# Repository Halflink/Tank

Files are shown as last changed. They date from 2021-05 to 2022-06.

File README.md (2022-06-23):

# Tank Project

### PROJECT
| Project name: | Halflink/Tank |
| --- | --- |
| Author: | Jeroen van Zwam |
| Date: | Summer 2019 |  
| Project type: | Raspberry Pi |

Additional information can be found in ./docs. Please read /docs/index.md for information on the documents.

### Executable

- Start ManualTank.py for console controlled running
- Start AutoTank.py for automatic running

### PROJECT DESCRIPTION
I started this project to see what you could do with a Pi. The goal is to create a
tracked robot which can roam around automatically.<br/>
Currently there are two operating modes:

1) roaming using ultrasonic sensor, by starting AutoTank.py
2) remote control using Xbox controller, by starting ManualTank.py

I chose the Devastator chassis as it came with the DC motors and it looks neat.

### PI INSTALLATION NOTES

- Set up SSH
- Set up WIFI
- Set up shared folder
- Set up Xbox controller https://pimylifeup.com/xbox-controllers-raspberry-pi/
- Use init.json to set up the GPIO ports

### PARTS LIST*

- Raspberry Py 3 zero
- Devastator Tank Mobile Robot Platform (Metal DC Gear Motor)
  https://elektronicavoorjou.nl/product/devastator-mobile-robot-metal-motor/
- L298N H-bridge Stepper Motor Driver
  https://www.kiwi-electronics.nl/l298n-module
- UBEC
  https://www.kiwi-electronics.nl/index.php?route=product/isearch&search=UBEC&description=true
- Xbox game console with bluetooth.
- HC-SR04 ultrasone sensor
  https://elektronicavoorjou.nl/product/hc-sr04-sensor/
- Custom holder for HC-SR04
  https://www.thingiverse.com/thing:2592461
  Designed by: https://www.thingiverse.com/alainducros/designs
  Manufactured by https://www.instagram.com/saydamcustomshop/

*) Please note that only the major parts are mentioned

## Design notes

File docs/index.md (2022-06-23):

#Index

## Design documents
**Fixation_articulée_pour_HC-SR04.zip**  
Thingiverse file for 3d printing custom part

**tank.fzz**  
This file contains the breadboard schema drawing fot my tank project.
.fzz is a fritzing file. You can download fritzing from https://fritzing.org/.

**tank_bb.png**
This file shows the breadboard of tank.fzz, so you can see the breadboard design without fritzing.
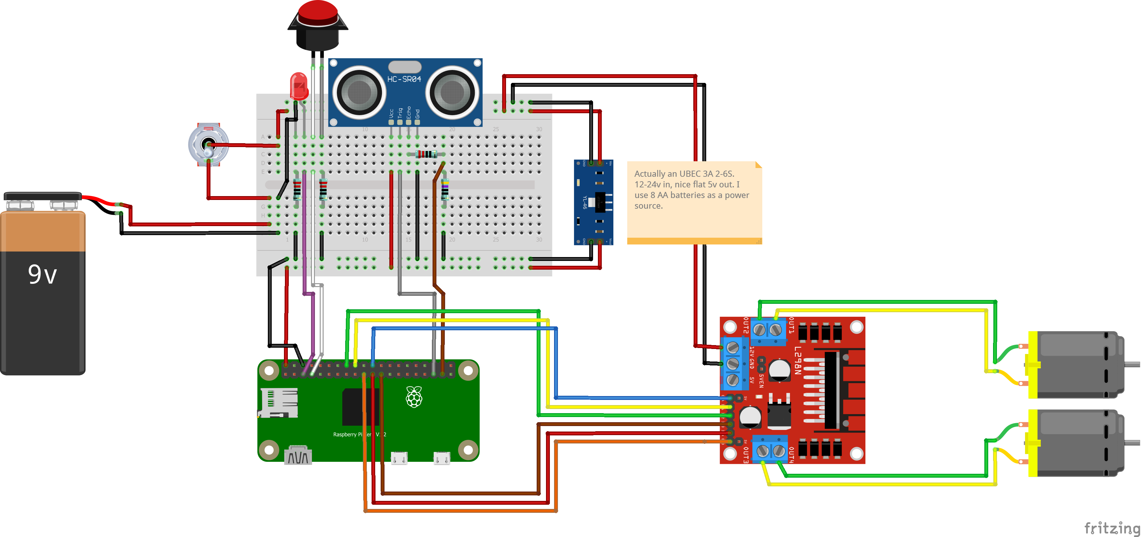
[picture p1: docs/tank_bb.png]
Custom head


**tank_pcb.fzz**  
This file contains an altered version from tank.fzz, where I optimized it for my PCB. Some components are missing here as they are to be connected using jumper wires.

## progress photos
**custom head.jpg**  
This is the PCB I had made on which to connect all components.  
Left you see one without the components, right with the components soldered on.
The LED I used for the distance blinking. It connects to the bottom-left connector together with the stop button.
Custom head

**Disassembled_1.jpg**  
Disassembled tank. You see the chassis, the top of the robot, and the head with some connectors to it.
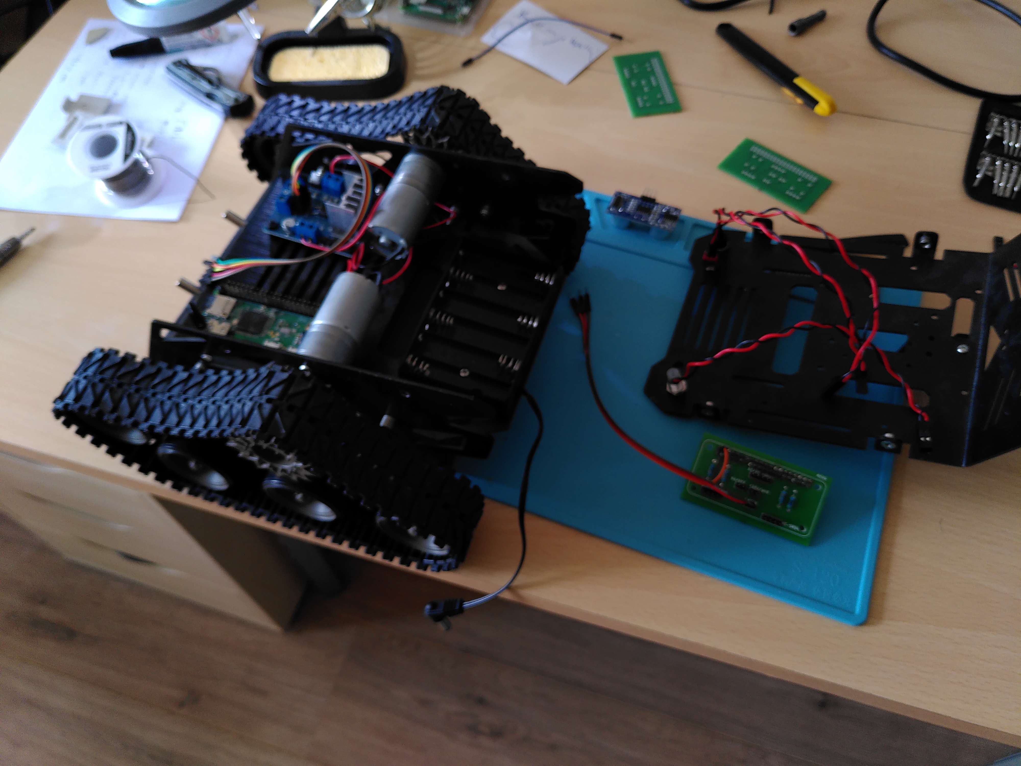
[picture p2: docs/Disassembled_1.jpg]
Disassembled tank


**Disassembled_added_custom head.jpg**  
At the bottom-left you see the PI-nano I used.  
On the top left the motor head which controls the motors you see top and bottom middle.  
At the right you see the battery pack to power the robot.
Tank components

**Disassembled_pi_nano.jpg**  
In this picture you see I added the head on the pi-nano.  
The motor head is connected to the GPIO ports.  
The red, orange and brown wires are not connected yet, but they are powering the head (12v, 5v, and ground)
Added custom head

**Tank.jpg**
Finished product
Added custom head

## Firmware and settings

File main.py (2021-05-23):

class TankMain:

    # import
    from evdev import InputDevice, categorize, ecodes
    import time as time
    from Chassis import Chassis
    from JsonHandler import JsonHandler
    import RPi.GPIO as GPIO

    class Axis:

        # Event_code: the event.code defining the axis.
        # The value from the event is ranged between 0 and 65568 we need
        # treshhold_max, treshhold_min and invert direction help translate that to -1, 0 and 1

        def __init__(self,
                     event_code,
                     treshhold_max,
                     treshhold_min,
                     invert_direction):

            self.treshhold_max = treshhold_max
            self.treshhold_min = treshhold_min
            self.event_code = event_code
            self.invert_direction = invert_direction
            self.current_value = 0

        def compare(self, event):
            return event.code == self.event_code

        def get_code(self):
            return self.event_code

        def get_direction(self, event):
            if event.value > self.treshhold_max:
                if self.invert_direction:
                    return -1
                else:
                    return 1
            elif event.value < self.treshhold_min:
                if self.invert_direction:
                    return 1
                else:
                    return -1
            else:
                return 0

    class Throttle:

        # Event_code: the event.code defining the throttle.
        # The value from the event is ranged between 0 and 256
        # treshhold_max helps translate that to 0 and 1

        def __init__(self,
                     event_code,
                     treshhold_max):

            self.treshhold_max = treshhold_max
            self.event_code = event_code

        def compare(self, event):
            return event.code == self.event_code

        def get_code(self):
            return self.event_code

        def get_value(self, event):
            if event.value > self.treshhold_max:
                return 1
            else:
                return 0

    # Variables
    continue_program = True
    x_direction = 0
    y_direction = 0
    right_throttle_value = 0
    left_throttle_value = 0

    def __init__(self):

        self.json_handler = self.JsonHandler()

        # set GPIO pins to Boardcom SOC channel numbering (defines how you refer to the pins)
        self.GPIO.setmode(self.GPIO.BCM)
        # GPIO 18 set up as input. It is pulled up to stop false signals
        self.GPIO.setup(self.json_handler.GPIO_stop_Button, self.GPIO.IN, pull_up_down=self.GPIO.PUD_UP)

        # creates object 'gamepad' to store the data
        self.game_pad = self.InputDevice(self.json_handler.game_pad_input_device)

        # EV_ABS event.code 0: x axis left joystick
        self.x_axis = self.Axis(0, 55000, 15000, False)

        # EV_ABS event.code 1: y axis left joystick
        self.y_axis = self.Axis(1, 55000, 15000, True)

        # EV_ABS event.code 9: right throttle
        self.right_throttle = self.Throttle(9, 100)

        # EV_ABS event.code 10: left throttle
        self.left_throttle = self.Throttle(10, 100)

        # set timer of last event handling
        self.time_event_handling = self.time.time()
        self.time_to_sleep = 0.25

        # set the chassis
        self.chassis = self.Chassis(self.GPIO
                                    , self.json_handler.GPIO_in1
                                    , self.json_handler.GPIO_in2
                                    , self.json_handler.GPIO_ena
                                    , self.json_handler.GPIO_in3
                                    , self.json_handler.GPIO_in4
                                    , self.json_handler.GPIO_enb)

    def stop_button_pressed(self, channel):
        print("Stop button pressed")
        self.continue_program = False

    def set_new_direction(self, event):

        change_direction = False

        # Set the direction
        if self.y_axis.compare(event) and self.y_direction != self.y_axis.get_direction(event):
            self.y_direction = self.y_axis.get_direction(event)
            change_direction = True
        elif self.x_axis.compare(event) and self.x_direction != self.x_axis.get_direction(event):
            self.x_direction = self.x_axis.get_direction(event)
            change_direction = True

        if change_direction:
            # check if the command is not too fast. If is, wait
            if self.time.time() - self.time_event_handling < self.time_to_sleep:
                self.time.sleep(self.time_to_sleep)

            # set last time
            self.time_event_handling = self.time.time()

            # redirect
            if self.y_direction == 1 and self.x_direction == 0:
                self.chassis.go_forward()
            elif self.y_direction == 1 and self.x_direction == 1:
                self.chassis.turn_right()
            elif self.y_direction == 1 and self.x_direction == -1:
                self.chassis.turn_left()
            elif self.y_direction == -1 and self.x_direction == 0:
                self.chassis.go_backward()
            elif self.y_direction == 0 and self.x_direction == 1:
                self.chassis.turn_right_axis()
            elif self.y_direction == 0 and self.x_direction == -1:
                self.chassis.turn_left_axis()
            elif self.y_direction == 0 and self.x_direction == 0:
                self.chassis.stop()

    def set_new_gear(self, event):

        change_gear = False

        if self.right_throttle.compare(event) and self.right_throttle_value != self.right_throttle.get_value(event):
            self.right_throttle_value = self.right_throttle.get_value(event)
            change_gear = True
        elif self.left_throttle.compare(event) and self.left_throttle_value != self.left_throttle.get_value(event):
            self.left_throttle_value = self.left_throttle.get_value(event)
            change_gear = True

        if change_gear:
            # check if the command is not too fast. If is, wait
            if self.time.time() - self.time_event_handling < self.time_to_sleep:
                self.time.sleep(self.time_to_sleep)

            # set last time
            self.time_event_handling = self.time.time()

            # change gear
            if self.right_throttle_value == 1 and self.left_throttle_value == 0:
                self.chassis.gear_up()
                print("Gear UP")
            elif self.right_throttle_value == 0 and self.left_throttle_value == 1:
                self.chassis.gear_down()
                print("Gear DOWN")

    def is_throttle(self, event):
        return self.right_throttle.compare(event) or self.left_throttle.compare(event)

    def is_axis(self, event):
        return self.x_axis.compare(event) or self.y_axis.compare(event)

    def run_tank(self):

        self.GPIO.add_event_detect(self.json_handler.GPIO_stop_Button
                                   , self.GPIO.FALLING
                                   , callback=self.stop_button_pressed
                                   , bouncetime=200)
        print("start")

        # evdev takes care of polling the controller in a loop
        for event in self.game_pad.read_loop():
            # filters by event type
            if not self.continue_program:
                print("hier dus")
                break
            elif event.type == self.ecodes.EV_KEY and event.code == 308:  # "Y"
                break
            elif event.type == self.ecodes.EV_ABS:
                if self.is_axis(event):
                    self.set_new_direction(event)
                elif self.is_throttle(event):
                    self.set_new_gear(event)

        print("en hier")
        self.chassis.quit()
        self.GPIO.cleanup()


if __name__ == '__main__':
    tank = TankMain()
    tank.run_tank()

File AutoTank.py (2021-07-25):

class AutoTank:

    # import
    import RPi.GPIO as GPIO
    import time
    import threading
    from Chassis import Chassis
    from JsonHandler import JsonHandler

    # variable
    continue_program = True

    class GreenLED(threading.Thread):

        # This class gets its own thread.

        # Declarations
        GPIO = None
        GPIO_green_LED = None
        time = None
        sleep_time_on = 0.5
        sleep_time_off = 0.5
        running = True

        def __init__(self, gpio, threading, time, gpio_green_led, name, thread_id):

            # set all variables
            self.threading = threading
            self.GPIO = gpio
            self.time = time

            # Set GPIO pins
            self.GPIO_green_LED = gpio_green_led
            self.GPIO.setup(self.GPIO_green_LED, self.GPIO.OUT)

            # initialize thread
            self.threading.Thread.__init__(self)
            self.threadID = thread_id
            self.name = name

        @staticmethod
        def calc_sleep_time(dist):

            calc_dist = 1
            if dist > 100:
                calc_dist = 100
            elif dist > 1:
                calc_dist = dist

            sleep_time = 2 * pow(0.8, (110 - calc_dist) / 10)

            return sleep_time

        def run(self):
            # Running the blinking light
            print("Starting " + self.name)
            while self.running:
                self.GPIO.output(self.GPIO_green_LED, self.GPIO.HIGH)
                self.time.sleep(self.sleep_time_on)
                self.GPIO.output(self.GPIO_green_LED, self.GPIO.LOW)
                self.time.sleep(self.sleep_time_off)
                print("sleep time = %.1f" % self.sleep_time_on)

        def set_blink_speed(self, on, off=None):

            if off is None:
                self.sleep_time_on = self.calc_sleep_time(on)
                self.sleep_time_off = self.sleep_time_on
            else:
                self.sleep_time_on = on
                self.sleep_time_off = off

        def terminate(self):
            # termination of the thread
            self.running = False

    def __init__(self):

        self.json_handler = self.JsonHandler()

        # set GPIO pins to Broadcom SOC channel numbering (defines how you refer to the pins)
        self.GPIO.setmode(self.GPIO.BCM)

        # set GPIO Pins
        self.GPIO_trigger = self.json_handler.GPIO_trigger
        self.GPIO_echo = self.json_handler.GPIO_echo
        self.GPIO_green_led = self.json_handler.GPIO_green_LED

        # set GPIO direction (IN / OUT)
        self.GPIO.setup(self.GPIO_trigger, self.GPIO.OUT)
        self.GPIO.setup(self.GPIO_echo, self.GPIO.IN)

        # GPIO 18 set up as input. It is pulled up to stop false signals
        self.GPIO.setup(self.json_handler.GPIO_stop_Button, self.GPIO.IN, pull_up_down=self.GPIO.PUD_UP)

        # set the chassis
        self.chassis = self.Chassis(self.GPIO,
                                    self.json_handler.GPIO_in1,
                                    self.json_handler.GPIO_in2,
                                    self.json_handler.GPIO_ena,
                                    self.json_handler.GPIO_in3,
                                    self.json_handler.GPIO_in4,
                                    self.json_handler.GPIO_enb,
                                    self.json_handler.cruise_speed_factor,
                                    self.json_handler.turn_speed_factor)

        # set the lights
        self.thread_green_led = self.GreenLED(self.GPIO,
                                              self.threading,
                                              self.time,
                                              self.GPIO_green_led,
                                              "Thread-1",
                                              1)

    def distance(self):

        # set Trigger to HIGH
        self.GPIO.output(self.GPIO_trigger, True)

        # set Trigger after 0.01ms to LOW
        self.time.sleep(0.00001)
        self.GPIO.output(self.GPIO_trigger, False)

        start_time = self.time.time()
        stop_time = self.time.time()

        # save StartTime
        while self.GPIO.input(self.GPIO_echo) == 0:
            start_time = self.time.time()

        # save time of arrival
        while self.GPIO.input(self.GPIO_echo) == 1:
            stop_time = self.time.time()

        # time difference between start and arrival
        time_elapsed = stop_time - start_time

        # multiply with the sonic speed (34300 cm/s)
        # and divide by 2, because there and back
        distance = (time_elapsed * 34300) / 2

        return distance

    def find_way(self):
        print("Finding way....")
        self.thread_green_led.set_blink_speed(0.1, 0.1)

        # determine distance
        dist = self.distance()

        # Back off from obstacle
        while dist < 20:
            dist = self.distance()
            print("Measured Distance = %.1f cm" % dist)
            self.time.sleep(0.25)
            self.chassis.go_backward()

        self.chassis.stop()
        current_dist = dist
        turn_time = 0.25
        turn_direction = "LEFT"

        # turn and check if there is room.
        # First try left, then try right, then left some more, etc.
        while dist < 40:
            if turn_direction == "LEFT":
                self.chassis.turn_left_axis()
                turn_direction = "RIGHT"
            else:
                self.chassis.turn_right_axis()
                turn_direction = "LEFT"

            turn_time = turn_time + 0.25
            self.time.sleep(turn_time)
            self.chassis.stop()
            dist = self.distance()
            print("Measured Distance = %.1f cm" % dist)

            if current_dist > dist:
                self.chassis.turn_left_axis()
                self.time.sleep(0.5)

            self.time.sleep(0.25)

    def drive(self):

        while self.continue_program:

            # determine distance
            dist = self.distance()

            # drive
            if dist < 30:
                self.chassis.stop()
                self.find_way()
            elif dist > 40:
                self.chassis.go_forward()

            # set blinking light
            self.thread_green_led.set_blink_speed(dist)

            print("Measured Distance = %.1f cm" % dist)
            self.time.sleep(1)

    def run_tank_on_auto(self):

        try:
            self.chassis.set_gear(self.json_handler.auto_cruise_speed)
            self.GPIO.add_event_detect(self.json_handler.GPIO_stop_Button,
                                       self.GPIO.FALLING,
                                       callback=self.stop_button_pressed,
                                       bouncetime=200)

            print("start")
            self.thread_green_led.start()
            self.drive()

        except KeyboardInterrupt:
            print("Measurement stopped by User")
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

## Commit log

2021-07-13 Initial commit. main.py assumes usage of console. Else you need to rename main and use AutoTank. To do: merge main and autotank into abstract, which are overrided by autotank and manualtank. main.py 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
    [tank.fzz]
2021-07-21 Added extra documentation. - breadboard update - PCB version - a PNG of the breadboard Please note that the wiring in doc differs from init.json. This is due to the fact that the new wiring is more c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
    [tank.fzz, tank_pcb.fzz]
2021-09-01 Added some more details on the project
    [tank_pcb.fzz]
